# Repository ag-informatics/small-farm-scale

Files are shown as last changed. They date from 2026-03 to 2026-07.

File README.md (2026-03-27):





# Welcome to your organization's demo respository
This code repository (or "repo") is designed to demonstrate the best GitHub has to offer with the least amount of noise.

The repo includes an `index.html` file (so it can render a web page), two GitHub Actions workflows, and a CSS stylesheet dependency.

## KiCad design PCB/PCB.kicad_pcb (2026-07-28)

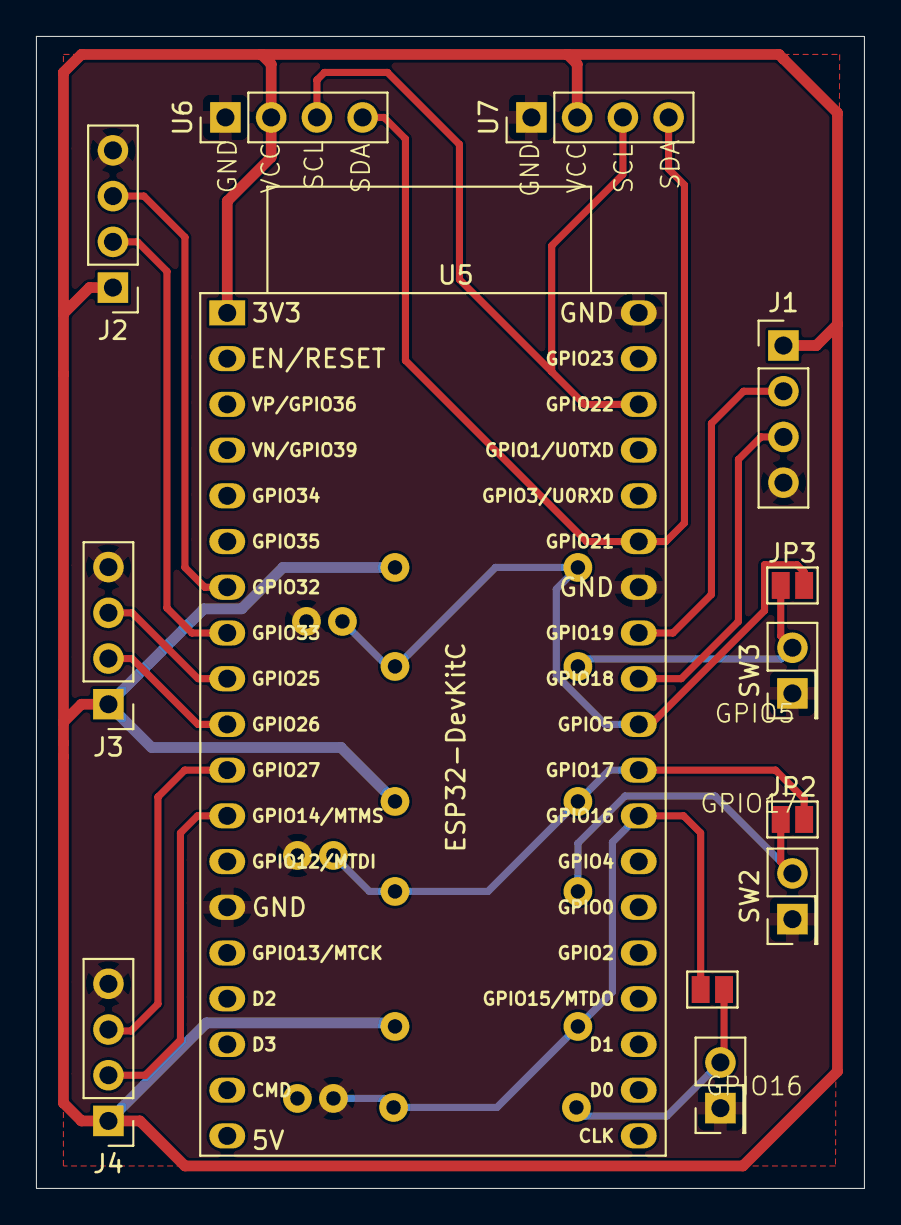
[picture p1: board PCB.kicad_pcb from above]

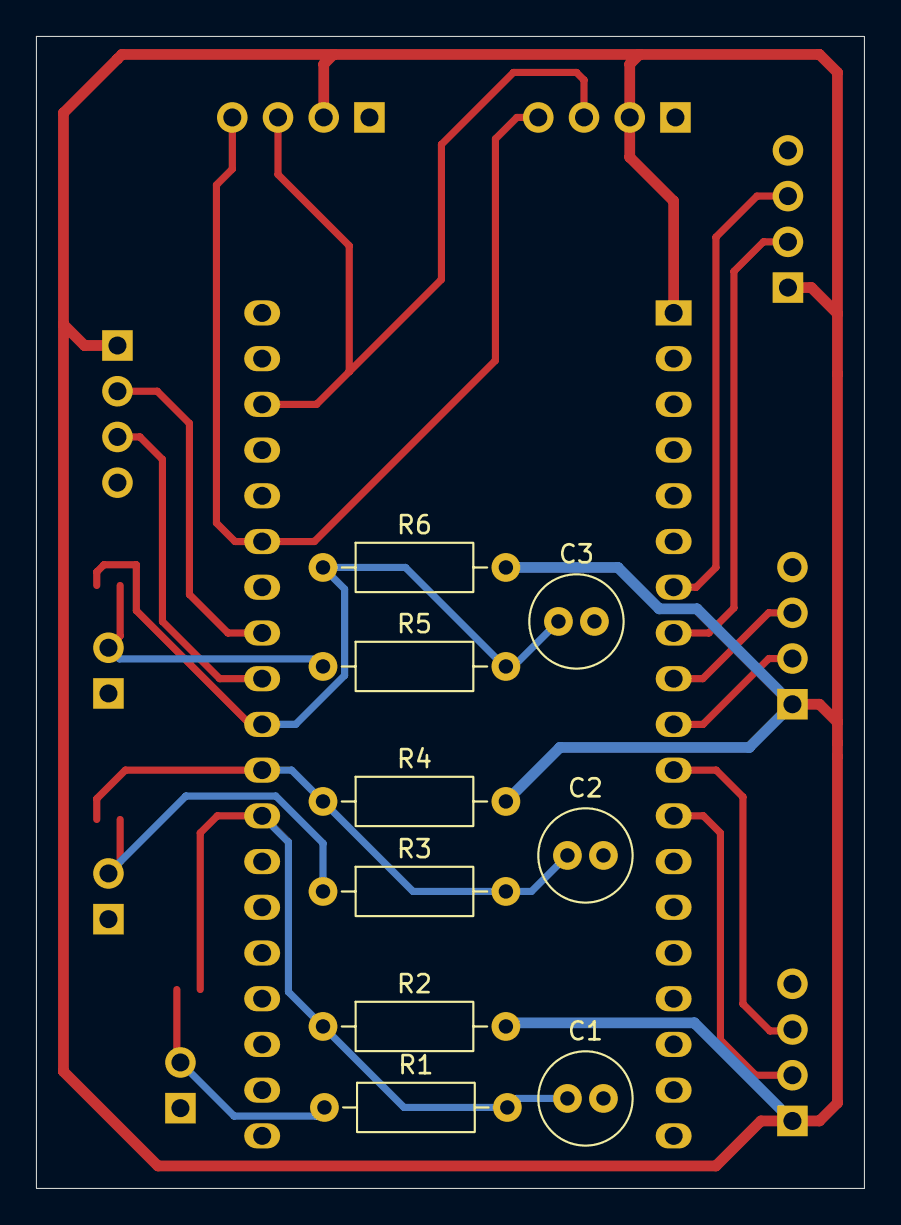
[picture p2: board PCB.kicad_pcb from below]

Board: 2 copper layers, 46.0 x 64.0 mm, 22 parts (9 on the bottom side), 18 nets.

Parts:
C1, C2, C3: 0.1uf; C_Radial_D5.0mm_H11.0mm_P2.00mm
J1, J2, J3, J4: Conn_01x04_Socket; PinHeader_1x04_P2.54mm_Vertical
JP1, JP2, JP3: Short this route to use software deboucer; SolderJumper-2_P1.3mm_Open_Pad1.0x1.5mm
R1, R3, R5: 1kΩ; R_Axial_DIN0207_L6.3mm_D2.5mm_P10.16mm_Horizontal
R2, R4, R6: 10kΩ; R_Axial_DIN0207_L6.3mm_D2.5mm_P10.16mm_Horizontal
SW1, SW2, SW3: SW_Push; PinHeader_2x01_P2.54mm_Vertical
U5: ESP32-DevKitC
U6: SD1306; PinHeader_1x04_P2.54mm_Vertical
U7: SD1309; PinHeader_1x04_P2.54mm_Vertical

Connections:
+3.3V: J1.1, J2.1, J3.1, J4.1, R2.2, R4.2, R6.2, U5.1 (3V3), U6.2 (VCC), U7.2 (VCC)
/BTN1: C1.1, JP1.2 (B), R1.2, R2.1, U5.27 (GPIO16)
/BTN2: C2.1, JP2.2 (B), R3.2, R4.1, U5.28 (GPIO17)
/BTN3: C3.1, JP3.2 (B), R5.2, R6.1, U5.29 (GPIO5)
/CLK1: J1.2, U5.31 (GPIO19)
/CLK2: J2.2, U5.8 (32K_XN/GPIO33/ADC1_CH5)
/CLK3: J3.2, U5.10 (DAC_2/ADC2_CH9/GPIO26)
/CLK4: J4.2, U5.12 (MTMS/GPIO14/ADC2_CH6)
/DATA1: J1.3, U5.30 (GPIO18)
/DATA2: J2.3, U5.7 (32K_XP/GPIO32/ADC1_CH4)
/DATA3: J3.3, U5.9 (DAC_1/ADC2_CH8/GPIO25)
/DATA4: J4.3, U5.11 (ADC2_CH7/GPIO27)
GND: C1.2, C2.2, C3.2, J1.4, J2.4, J3.4, J4.4, SW1.1, SW2.1, SW3.1, U5.14 (GND), U5.32 (GND), U5.38 (GND), U6.1 (GND), U7.1 (GND)
unnamed: JP1.1 (A), R1.1, SW1.2
unnamed: JP2.1 (A), R3.1, SW2.2
unnamed: JP3.1 (A), R5.1, SW3.2
unnamed: U5.33 (GPIO21), U6.4 (SDA), U7.4 (SDA)
unnamed: U5.36 (GPIO22), U6.3 (SCL), U7.3 (SCL)

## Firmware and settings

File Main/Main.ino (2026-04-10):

#include <SPI.h>
#include <Wire.h>
#include <Adafruit_GFX.h>
#include <Adafruit_SSD1306.h>
#include <Adafruit_HX711.h>
#include <WiFi.h>
#include <credential.h>
#include <HTTPClient.h>
#include <ArduinoJson.h> 

//WiFi information
const char* ssid = STASSID;
const char* password = STAPSK;

//AirTable credential
const char* token = AIRTABLE_KEY;

#define SCREEN_WIDTH 128 // OLED display width, in pixels
#define SCREEN_HEIGHT 64 // OLED display height, in pixels

#define OLED_RESET     -1 // Reset pin # (or -1 if sharing Arduino reset pin)
#define SCREEN_ADDRESS 0x3C
Adafruit_SSD1306 display(SCREEN_WIDTH, SCREEN_HEIGHT, &Wire, OLED_RESET);
const int buttonPinA = 16;
const int buttonPinB = 17;
const int buttonPinC = 5;

// Load Cell Pins
const uint8_t DATA_PIN_1 = 18;  
const uint8_t CLOCK_PIN_1 = 19; 

const uint8_t DATA_PIN_2 = 32;  
const uint8_t CLOCK_PIN_2 = 33; 

const uint8_t DATA_PIN_3 = 25;  
const uint8_t CLOCK_PIN_3 = 26; 

const uint8_t DATA_PIN_4 = 27;  
const uint8_t CLOCK_PIN_4 = 14;

Adafruit_HX711 hx711_1(DATA_PIN_1, CLOCK_PIN_1);
Adafruit_HX711 hx711_2(DATA_PIN_2, CLOCK_PIN_2);
Adafruit_HX711 hx711_3(DATA_PIN_3, CLOCK_PIN_3);
Adafruit_HX711 hx711_4(DATA_PIN_4, CLOCK_PIN_4);


typedef enum {
  MAINSTATE,
  UPLOADCONF,
  WEIGHTCHANGE,
  UPLOADED,
  CROPCHANGE
} State;

State state;
float weight; // Will replace with function I assume?
String date = "2/26/2026"; // to replace
String buttonText;
String weightText;
float measureWeight;
float offset;
boolean uploaded = false;

// Buttons
const unsigned long DEBOUNCE_DELAY = 300;  // in milliseconds
volatile unsigned long lastPressTimeA = 0;
volatile unsigned long lastPressTimeB = 0;
volatile unsigned long lastPressTimeC = 0;

void setup() {
  Serial.begin(9600);
  Serial.begin(115200);
  delay(500);

  if(!display.begin(SSD1306_SWITCHCAPVCC, SCREEN_ADDRESS)) {
    Serial.println(F("SSD1306 allocation failed"));
    for(;;); // Don't proceed, loop forever
  }
  display.display();
  delay(1000);
  display.clearDisplay();
  
  display.setTextColor(SSD1306_WHITE);
  display.cp437(true);         // Use full 256 char 'Code Page 437' font

  pinMode(buttonPinA, INPUT_PULLUP);
  pinMode(buttonPinB, INPUT_PULLUP);
  pinMode(buttonPinC, INPUT_PULLUP);
  attachInterrupt(buttonPinA, buttonISRA, RISING);
  attachInterrupt(buttonPinB, buttonISRB, RISING);
  attachInterrupt(buttonPinC, buttonISRC, RISING);

  // Load Cell Setup
  hx711_1.begin();
  hx711_2.begin();
  hx711_3.begin();
  hx711_4.begin();

  for (uint8_t t=0; t<3; t++) {
      hx711_1.tareA(hx711_1.readChannelRaw(CHAN_A_GAIN_128));
      hx711_1.tareA(hx711_1.readChannelRaw(CHAN_A_GAIN_128));
      
      hx711_2.tareA(hx711_2.readChannelRaw(CHAN_A_GAIN_128));
      hx711_2.tareA(hx711_2.readChannelRaw(CHAN_A_GAIN_128));

      hx711_3.tareA(hx711_3.readChannelRaw(CHAN_A_GAIN_128));
      hx711_3.tareA(hx711_3.readChannelRaw(CHAN_A_GAIN_128));

      hx711_4.tareA(hx711_4.readChannelRaw(CHAN_A_GAIN_128));
      hx711_4.tareA(hx711_4.readChannelRaw(CHAN_A_GAIN_128));
    }

  offset = 0;
  state = MAINSTATE;

  //  WiFi setup
  WiFi.mode(WIFI_STA);
  WiFi.begin(ssid, password);
  Serial.print("Connecting to WiFi ..");
  while (WiFi.status() != WL_CONNECTED) {
    Serial.print('.');
    delay(1000);
  }
  Serial.println(WiFi.localIP());
}

void loop() {
  display.clearDisplay();
  switch (state) {
    case MAINSTATE:
      weigh();
      weightText = String(weight) + " lb";
      if (weightText == "-0.00 lb") {
        weightText = "0.00 lb";
      }
      drawMainState();
      break;
    case UPLOADCONF:
      drawUploadConf();
      break;
    case WEIGHTCHANGE:
      drawWeightChange();
      break;
    case UPLOADED:
      if (!uploaded) {
        upload();
        uploaded = true;
      }
      drawUploaded();
      break;
    case CROPCHANGE:
      drawCropChange();
      break;
  }
  // Display Date
  display.setTextSize(1);
  display.setCursor(SCREEN_WIDTH - date.length()*6,0);
  display.println(date);
  
  // Display Button Descriptions
  display.setCursor(0, 56);
  display.println(buttonText);
  display.display();
  delay(20);
}

// Interrupt Service Routines (ISR)
// Red Button
void ARDUINO_ISR_ATTR buttonISRA() {
  unsigned long now = millis(); // current time
  if (now - lastPressTimeA > DEBOUNCE_DELAY) {
    State oldstate = state;
    switch (state) {
      case MAINSTATE:
        offset = measureWeight;
        break;
      case UPLOADCONF:
        state = MAINSTATE;
        break;
      case WEIGHTCHANGE:
        // change weight type to type 1 idk
        state = UPLOADED;
        break;
      case UPLOADED:
        state = MAINSTATE;
        uploaded = false;
        break;
      case CROPCHANGE:
        // go up to next crop
        break;
    } 
  }
  lastPressTimeA = now;
}

// Blue Button
void ARDUINO_ISR_ATTR buttonISRB() {
  unsigned long now = millis(); // current time
  if (now - lastPressTimeB > DEBOUNCE_DELAY) {
    State oldstate = state;
    switch (state) {  
      case MAINSTATE:
        state = UPLOADCONF;
        break;
      case UPLOADCONF:
//        state = WEIGHTCHANGE;
// Tam changed this part for dry run
        state = UPLOADED;
        break;
      case WEIGHTCHANGE:
        // change weight type to type 2 idk
        state = UPLOADED;
        break;
      case UPLOADED:
        // N/A
        break;
      case CROPCHANGE:
        state = MAINSTATE;
        break;
    } 
  }
  lastPressTimeB = now;
}

// Yellow Button
void ARDUINO_ISR_ATTR buttonISRC() {
  unsigned long now = millis(); // current time
  if (now - lastPressTimeC > DEBOUNCE_DELAY) {
    State oldstate = state;
    switch (state) {  
      case MAINSTATE:
        state = CROPCHANGE;
        break;
      case UPLOADCONF:
        weight *= -1;
        break;
      case WEIGHTCHANGE:
        // change weight type to type 3 idk
        state = UPLOADED;
        break;
      case UPLOADED:
        // n/a
        break;
      case CROPCHANGE:
        // go down in the crop scrolling
        break;
    } 
  }
  lastPressTimeC = now;
}

// State Drawing Functions

// DONE
void drawMainState() {
  buttonText = "ZERO  UPLOAD  NEWCROP";
  // Display Weight
  display.setTextSize(2);
  display.setCursor((SCREEN_WIDTH - weightText.length()*12)/2, 20);
  display.println(weightText);
}

//  NEED MORE SPACE (should be fine with big screen)
void drawUploadConf() {
  display.setTextSize(2);
  display.setCursor((SCREEN_WIDTH - 6*12)/2, 18);
  display.println("Upload");
  display.setCursor((SCREEN_WIDTH - (weightText.length()+1)*12)/2, 35);
  display.println(weightText + "?");
  buttonText = "BACK    UPLOAD    NEG";
}

// NEED INFO ON WEIGHT TYPES
void drawWeightChange() {
  display.setTextSize(1);
  display.setCursor((SCREEN_WIDTH - 18*6)/2, 20);
  display.println("Select Weight Type");
  buttonText = "TYPE1   TYPE2   TYPE3";
}

void upload() {
  // Add upload function here for now. We should reorganize code later
  HTTPClient https;
  // The URL is Base ID / Table ID
  https.begin("https://api.airtable.com/v0/appYERzq7g8wEpx5M/tblC6ko92LRuh9Qef/"); 
  // Set headers with AirTable Token
  https.addHeader("Content-Type", "application/json");
  https.addHeader("Authorization", "Bearer " + String(token));
  // Create a payload package
  StaticJsonDocument<256> payload; 
  JsonObject scale = payload.createNestedObject("fields");
  scale["Wieght"] = weight;
  scale["Crop"] = "Onion";
  // Prepare data for an API call  
  String requestBody;
  serializeJson(payload, requestBody);
  // Send a request  
  int httpResponseCode = https.POST(requestBody);
  Serial.printf("Response: %d\n", httpResponseCode);
  https.end(); 
  uploaded = true;
}

// DONE
void drawUploaded() {
  display.setTextSize(2);
  display.setCursor((SCREEN_WIDTH - weightText.length()*12)/2, 18);
  display.println(weightText);
  display.setCursor((SCREEN_WIDTH - 8*12)/2, 35);
  display.println("Uploaded");
  buttonText = "CONTINUE";
}

// NEED INFO ON CROPS
void drawCropChange() {
  display.setTextSize(2);
  display.setCursor((SCREEN_WIDTH - 10*12)/2, 20);
  display.println("CropChange");
  buttonText = " UP    SELECT    DOWN";
}

// Weight Collecting
void weigh() {
  int32_t weight_1 = hx711_1.readChannelBlocking(CHAN_A_GAIN_128);
  int32_t weight_2 = hx711_2.readChannelBlocking(CHAN_A_GAIN_128);
  int32_t weight_3 = hx711_3.readChannelBlocking(CHAN_A_GAIN_128);
  int32_t weight_4 = hx711_4.readChannelBlocking(CHAN_A_GAIN_128);
  int64_t total_weight = weight_1 + weight_2 + weight_3 + weight_4;
  measureWeight = total_weight / (-428.0);
  measureWeight /= 453.592;
  weight = measureWeight - offset;
}

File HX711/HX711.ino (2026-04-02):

#include "Adafruit_HX711.h"

// Define the pins for the HX711 communication
const uint8_t DATA_PIN_1 = 18;  
const uint8_t CLOCK_PIN_1 = 19; 

const uint8_t DATA_PIN_2 = 32;  
const uint8_t CLOCK_PIN_2 = 33; 

const uint8_t DATA_PIN_3 = 25;  
const uint8_t CLOCK_PIN_3 = 26; 

const uint8_t DATA_PIN_4 = 27;  
const uint8_t CLOCK_PIN_4 = 14; 

Adafruit_HX711 hx711_1(DATA_PIN_1, CLOCK_PIN_1);
Adafruit_HX711 hx711_2(DATA_PIN_2, CLOCK_PIN_2);
Adafruit_HX711 hx711_3(DATA_PIN_3, CLOCK_PIN_3);
Adafruit_HX711 hx711_4(DATA_PIN_4, CLOCK_PIN_4);

void setup() {
  Serial.begin(115200);

  // wait for serial port to connect. Needed for native USB port only
  while (!Serial) {
    delay(10);
  }

  // Initialize the HX711
  hx711_1.begin();
  hx711_2.begin();
  hx711_3.begin();
  hx711_4.begin();

  // read and toss 3 values each
  Serial.println("Tareing....");
  for (uint8_t t=0; t<3; t++) {
    hx711_1.tareA(hx711_1.readChannelRaw(CHAN_A_GAIN_128));
    hx711_1.tareA(hx711_1.readChannelRaw(CHAN_A_GAIN_128));
    
    hx711_2.tareA(hx711_2.readChannelRaw(CHAN_A_GAIN_128));
    hx711_2.tareA(hx711_2.readChannelRaw(CHAN_A_GAIN_128));

    hx711_3.tareA(hx711_3.readChannelRaw(CHAN_A_GAIN_128));
    hx711_3.tareA(hx711_3.readChannelRaw(CHAN_A_GAIN_128));

    hx711_4.tareA(hx711_4.readChannelRaw(CHAN_A_GAIN_128));
    hx711_4.tareA(hx711_4.readChannelRaw(CHAN_A_GAIN_128));
  }
} 

void loop() {
  // Read from Channel A with Gain 128, can also try CHAN_A_GAIN_64 or CHAN_B_GAIN_32
  // since the read is blocking this will not be more than 10 or 80 SPS (L or H switch)
  int32_t weight_1 = hx711_1.readChannelBlocking(CHAN_A_GAIN_128);
  Serial.print("Load Cell 1: ");
  Serial.println(weight_1);
  
  int32_t weight_2 = hx711_2.readChannelBlocking(CHAN_A_GAIN_128);
  Serial.print("Load Cell 2: ");
  Serial.println(weight_2);

  int32_t weight_3 = hx711_3.readChannelBlocking(CHAN_A_GAIN_128);
  Serial.print("Load Cell 3: ");
  Serial.println(weight_3);

  int32_t weight_4 = hx711_4.readChannelBlocking(CHAN_A_GAIN_128);
  Serial.print("Load Cell 4: ");
  Serial.println(weight_4);

  int64_t total_weight = weight_1 + weight_2 + weight_3 + weight_4;
  Serial.print("Total weight: ");
  Serial.println(total_weight);

  float total_weight_grams = total_weight / (-428.0) ;
  Serial.print("Total weight (g): ");
  Serial.println(total_weight_grams);
  
  delay(500);
  Serial.println();
}

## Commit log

2026-03-31 first calibration profile
2026-04-02 update calibration profile
2026-04-10 Fixed Upload Bug and -0
    [Main.ino]
2026-07-04 create pcb project
    [PCB.kicad_pcb, PCB.kicad_sch]
2026-07-04 add symbols
    [PCB.kicad_pcb, PCB.kicad_sch]
2026-07-05 Connect parts
    [PCB.kicad_sch]
2026-07-05 Finished layout
    [PCB.kicad_pcb, PCB.kicad_sch]
2026-07-08 Put all trace in the front
    [PCB.kicad_pcb]
2026-07-08 create custom esp32 footprint
2026-07-08 update esp32-38 pin footprint
2026-07-09 update pcb
    [PCB.kicad_pcb, PCB.kicad_sch]
2026-07-11 Fixed spacing and orientation of HX711 pins
    [PCB.kicad_pcb]
2026-07-13 Add capacitor
    [PCB.kicad_pcb, PCB.kicad_sch]
2026-07-15 Change push button connection
    [PCB.kicad_pcb, PCB.kicad_sch]
2026-07-19 Add hardware deboucers at push buttons
    [PCB.kicad_sch]
2026-07-28 backup before routing hw debouncer
    [PCB.kicad_pcb, PCB.kicad_sch]
2026-07-28 pcb edits
    [PCB.kicad_pcb]
